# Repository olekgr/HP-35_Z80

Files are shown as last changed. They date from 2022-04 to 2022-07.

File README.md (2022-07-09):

# HP-35-Z80
Build HP35 scientic calculator clone with Z80 cpu from scratch.

## Intro

This DIY page is about building a HP35 clone. But without using emulators, HP microcode etc. I have always wanted to write original algorithms, created by David S. Cochran and provided by William E. Egbert in 4 editions of 1977's HP Journal, please see <a href="https://github.com/olekgr/HP-35_Z80/tree/main/arch">arch</a>.

As the original HP35 was built 50 years ago, this is a good time to do the same.

All fuctions are written with BCD arithmetic, I haven't used BCD - to binary conversion.

## Number format

For this HP35 clone, I chose a BCD floating point format. It uses an exponent byte, a sign byte and eight bytes of fractional part  (80 bits total). 

The sign byte holds 0x00 for positive numbers and 0x09 for negative, this byte also can hold other values in case of positive or negative overflow.

The exponent byte is the signed number power of 10, plus the offset 0x80. Note that exponent is not in BCD form, but binary. This greatly simplifies addition and substraction algorithms. Range is limited to 10^-99 and 10^99.

The fractional part is represented as 16 BCD digits packed two per byte, with an implied decimal point after the first digit (normalized form).

Only the first 12 digits are always displayed to the user; the last 4 digits exists to maintain precision (guard digits). All internal calculations are done with 16 digits, next the displayed result is always rounded to 12 digits.

As an examples:

1 is stored as 80_00_10_00_00_00_00_00_00_00

0.1 is stored as 7f_00_10_00_00_00_00_00_00_00

123 is stored as 82_00_12_30_00_00_00_00_00_00

pi/4 is stored  as 7f_00_78_53_98_16_33_97_44_83

## Negative numbers

Negative numbers are always stored as their 10's complement, with 0x09 at sign position. For example:

-1 is stored as 80_09_90_00_00_00_00_00_00_00

-12 is stored as 81_09_88_00_00_00_00_00_00_00

## Why Z80?

The Z80 is only four years younger than the HP35 :)

It has few instructions useful for making BCD arithmetic:

* RLD - rotate left decimal (used for shifting BCD numbers to the left)

* RRD - rotate right decimal (used for shifting BCD numbers to the right)

* DAA - decimal accumulator adjust (addition and substraction of BCD numbers)

## Speed

Calculations are fast, much faster than original HP35, we get the result immediately after pressing the key.

## Operating

I have made every effort to make this calculator work exactly like the original. Some functions were simple, others (most notably the CHS key which changes the sign of a number before or after it was entered) difficult. Either way, the calculator executes all the examples in the HP35 manual the same way. I have to say I use this calculator every day and it does a great job.

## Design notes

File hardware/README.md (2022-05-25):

# HP-35-Z80
EAGLE PCB source files, schematic, gerbers etc.

## Hardware
The hardware is made as simple as possible. It consists of a Z80 CPU, 8K RAM, 8K ROM, input and output buffers and a simple address decoder. The main program takes about 6K, so it fits easily in 8K EEPROM. I chose 8K RAM (6264) only and because of availability, not need, I think 1-2K would be enough for stack and variables.

## Memory map
0000h-2000h ROM

8000h-A000h RAM

## BOM
* IC1 - Z80 - main CPU
* IC2 - AT28C64 - ROM
* IC3 - 6264 - RAM
* IC4 - 74HCT32 - control signals (memory read, write)
* IC5 - 74HCT154 - display multiplexer
* IC6 - 74HCT138 - address decoder (only 3 periph used)
* IC7 - 74HCT541 - keyboard input
* IC8, IC9 - 74HCT574 - digit and position for multiplexing 7-seg display
* OSC - 8MHz DIL14 - main clock

All SMT components in 1206 case (except C11 - "D" case)
* C1 - 10u 
* R1..R9 - 10k 
* C2..C10 100n
* R10..R17 - 220R (HP used inductors here for power saving :)
* DIS1..4 - common cathode 4x7 segment display (eg. SH5461AS)
* X1,X2 - USB MINI sockets (+5V power supply, for convenience left and right side)
* keys 1..35 Cherry MX switches

## Errors

None found :)

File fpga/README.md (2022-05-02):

# HP-35-Z80
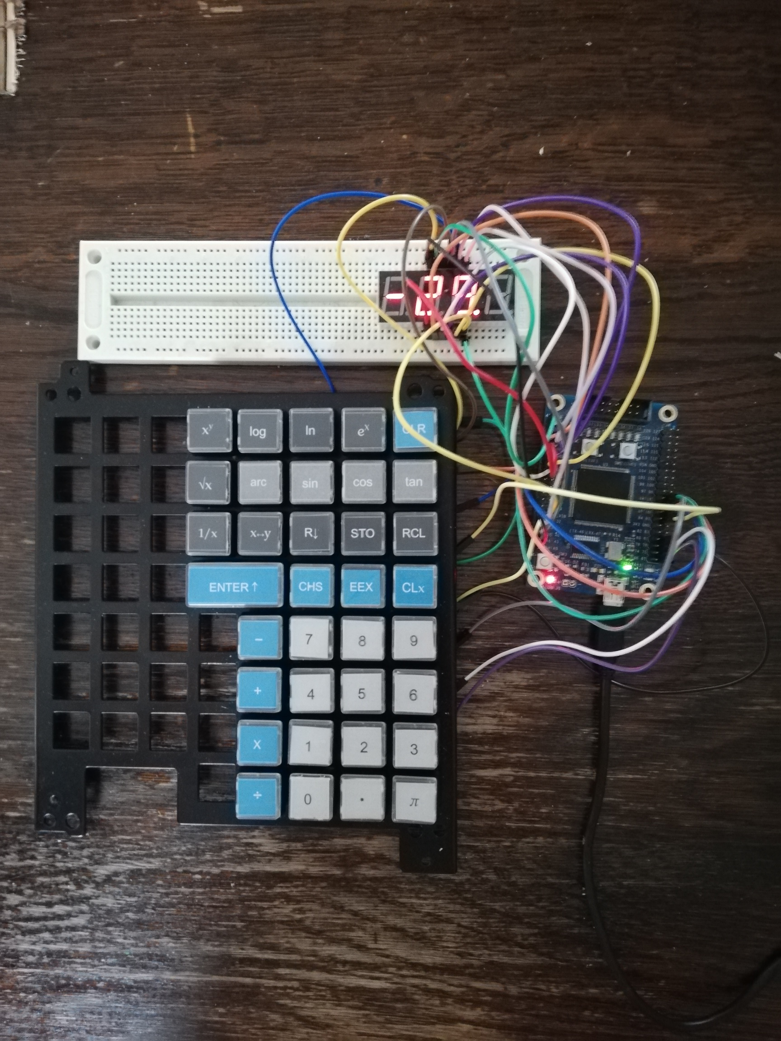
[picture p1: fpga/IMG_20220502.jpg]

What is FPGA doing in this project? Well, beeing VHDL fan, all work on the HP35 clone was done on the thing shown in the photo. In the xilinx XC6SLX9 I implemented the T80 core from Opencores with all accompanying circuits. The keyboard is from an old cash register. And only one 4 digit display.

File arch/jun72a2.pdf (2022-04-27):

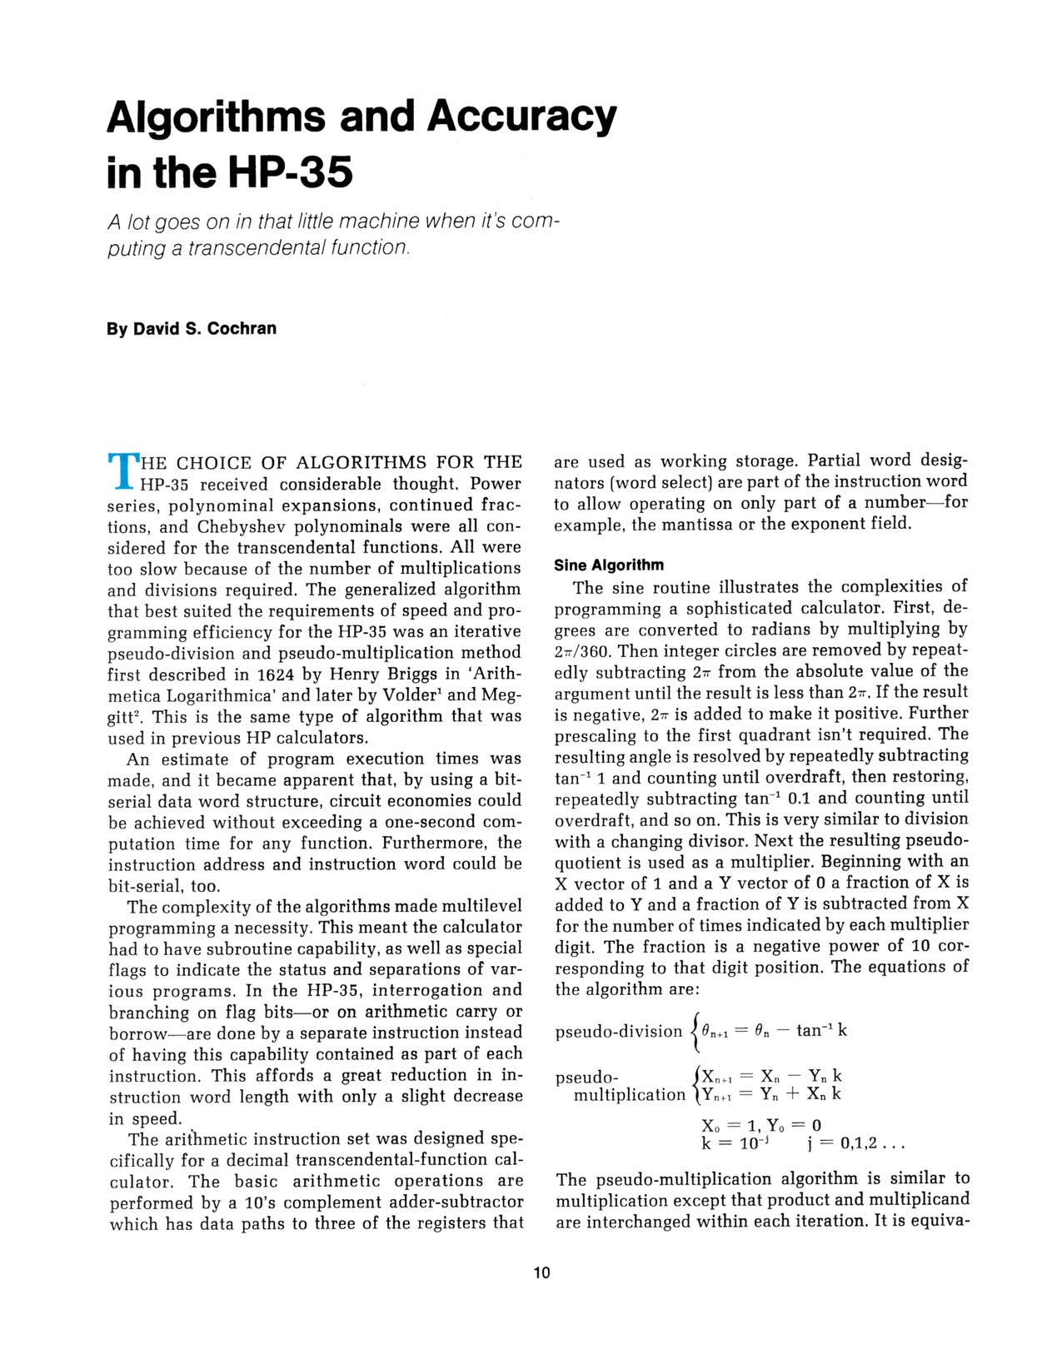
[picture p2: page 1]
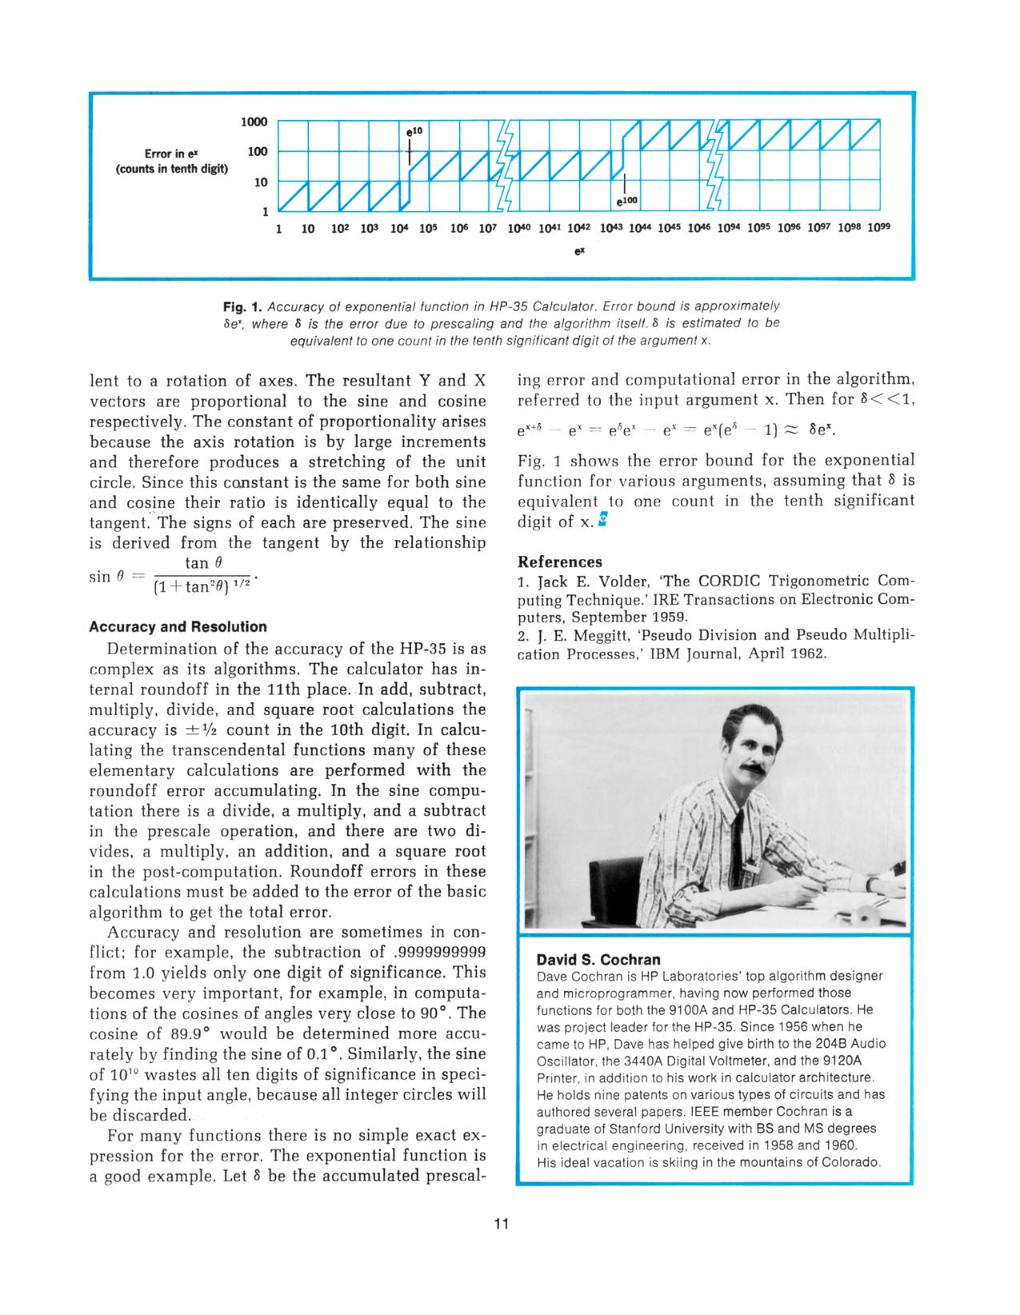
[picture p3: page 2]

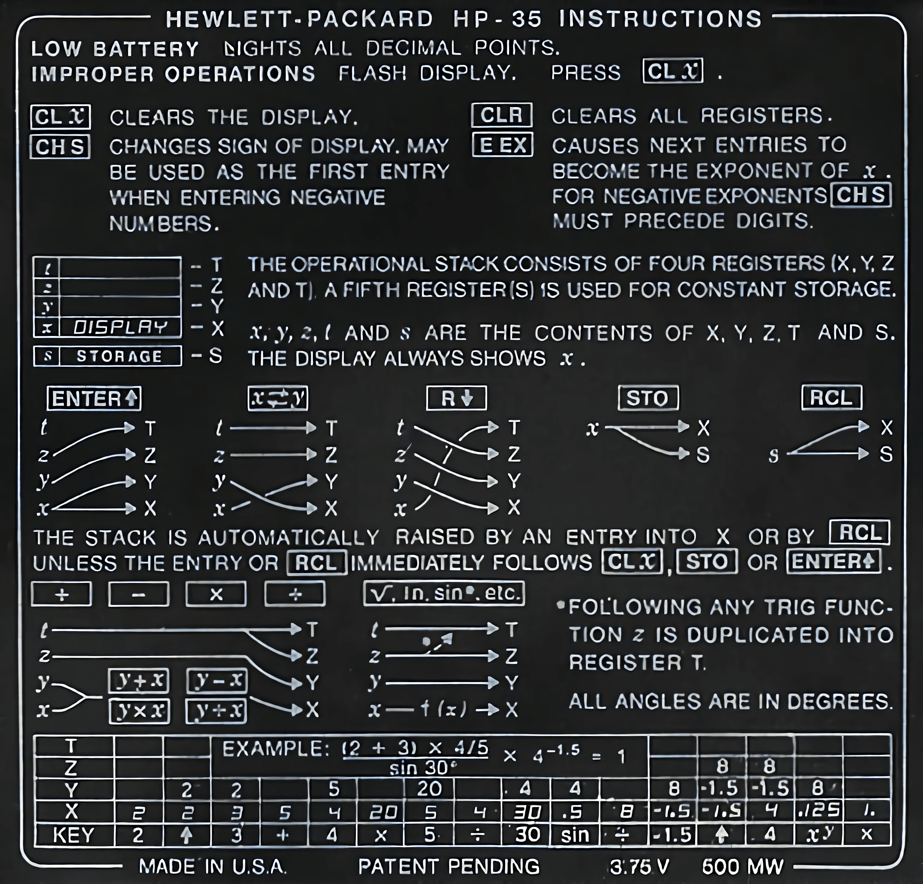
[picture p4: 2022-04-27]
arch/HP35_Backlabel.png

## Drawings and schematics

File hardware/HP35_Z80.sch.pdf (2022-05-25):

8Q | 12 7Q | 13 6Q | 14 5Q | 15 4Q | 16 3Q | 17 2Q | 18 1Q | 19
8Q | 12 7Q | 13 6Q | 14 5Q | 15 4Q | 16 3Q | 17 2Q | 18 1Q | 19

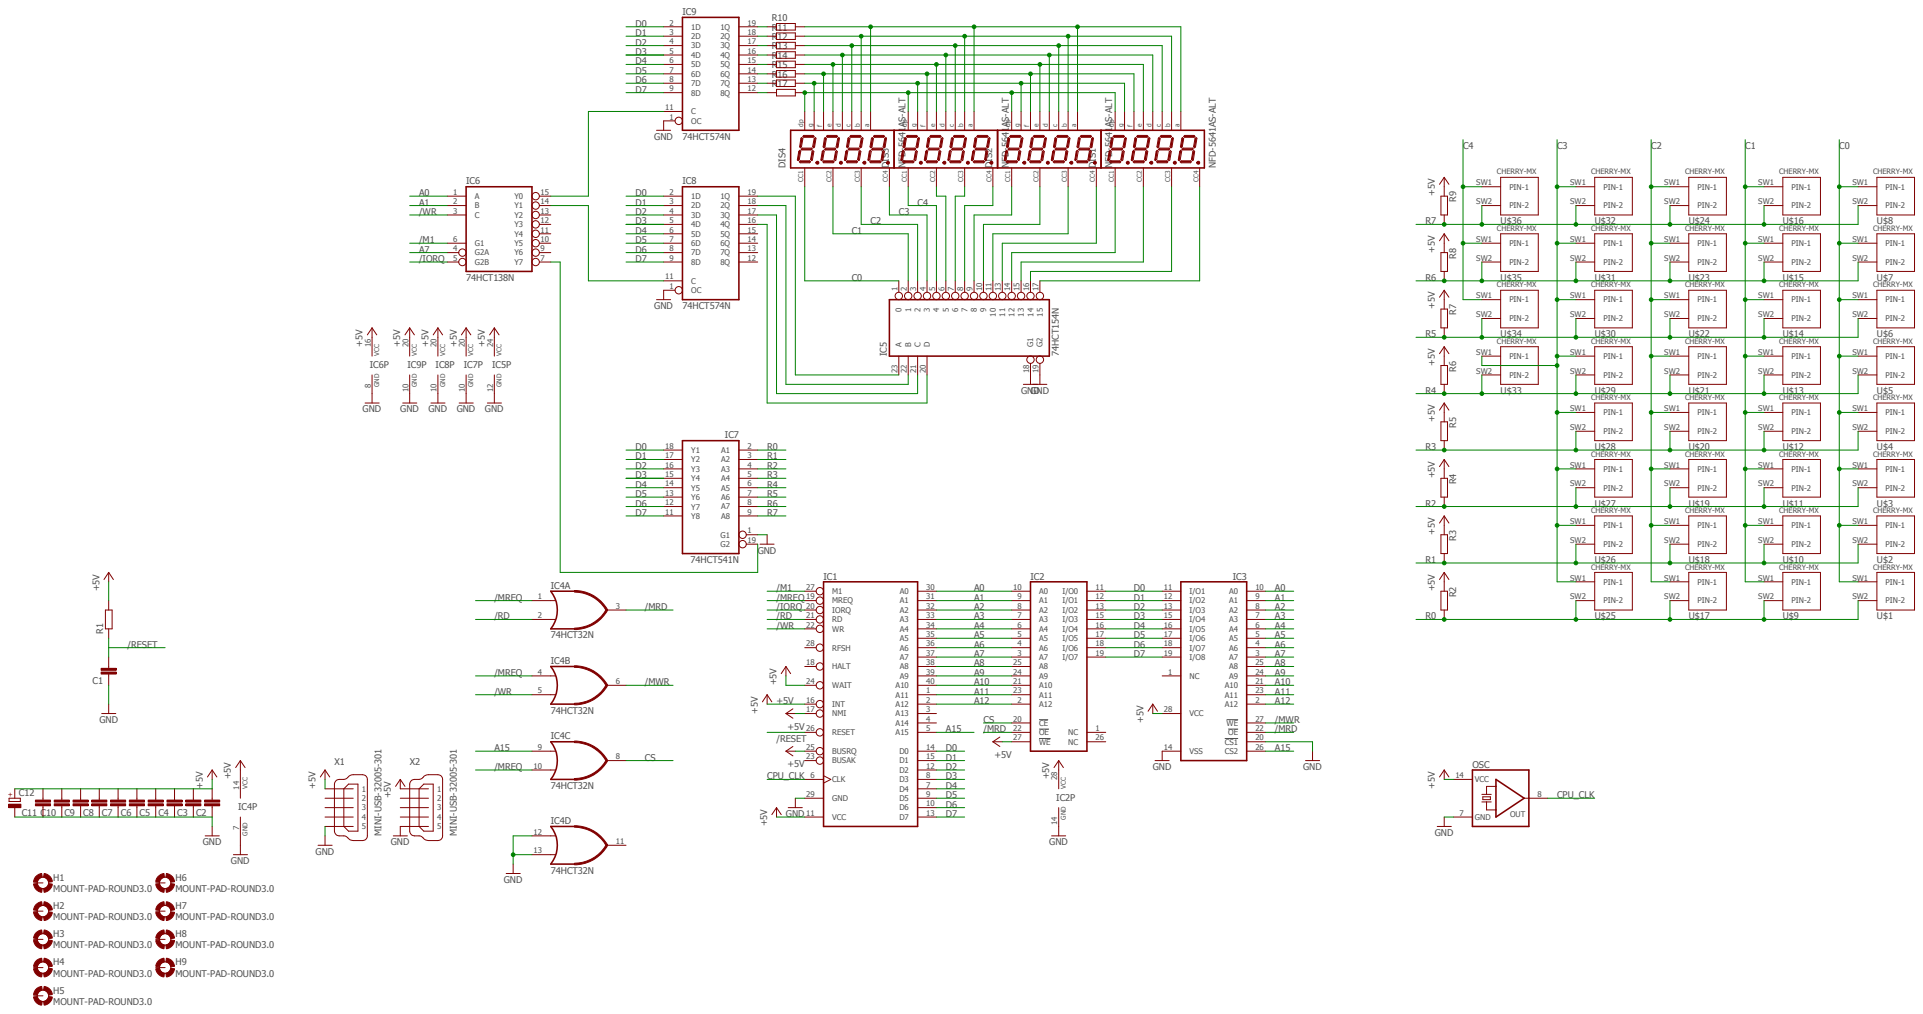
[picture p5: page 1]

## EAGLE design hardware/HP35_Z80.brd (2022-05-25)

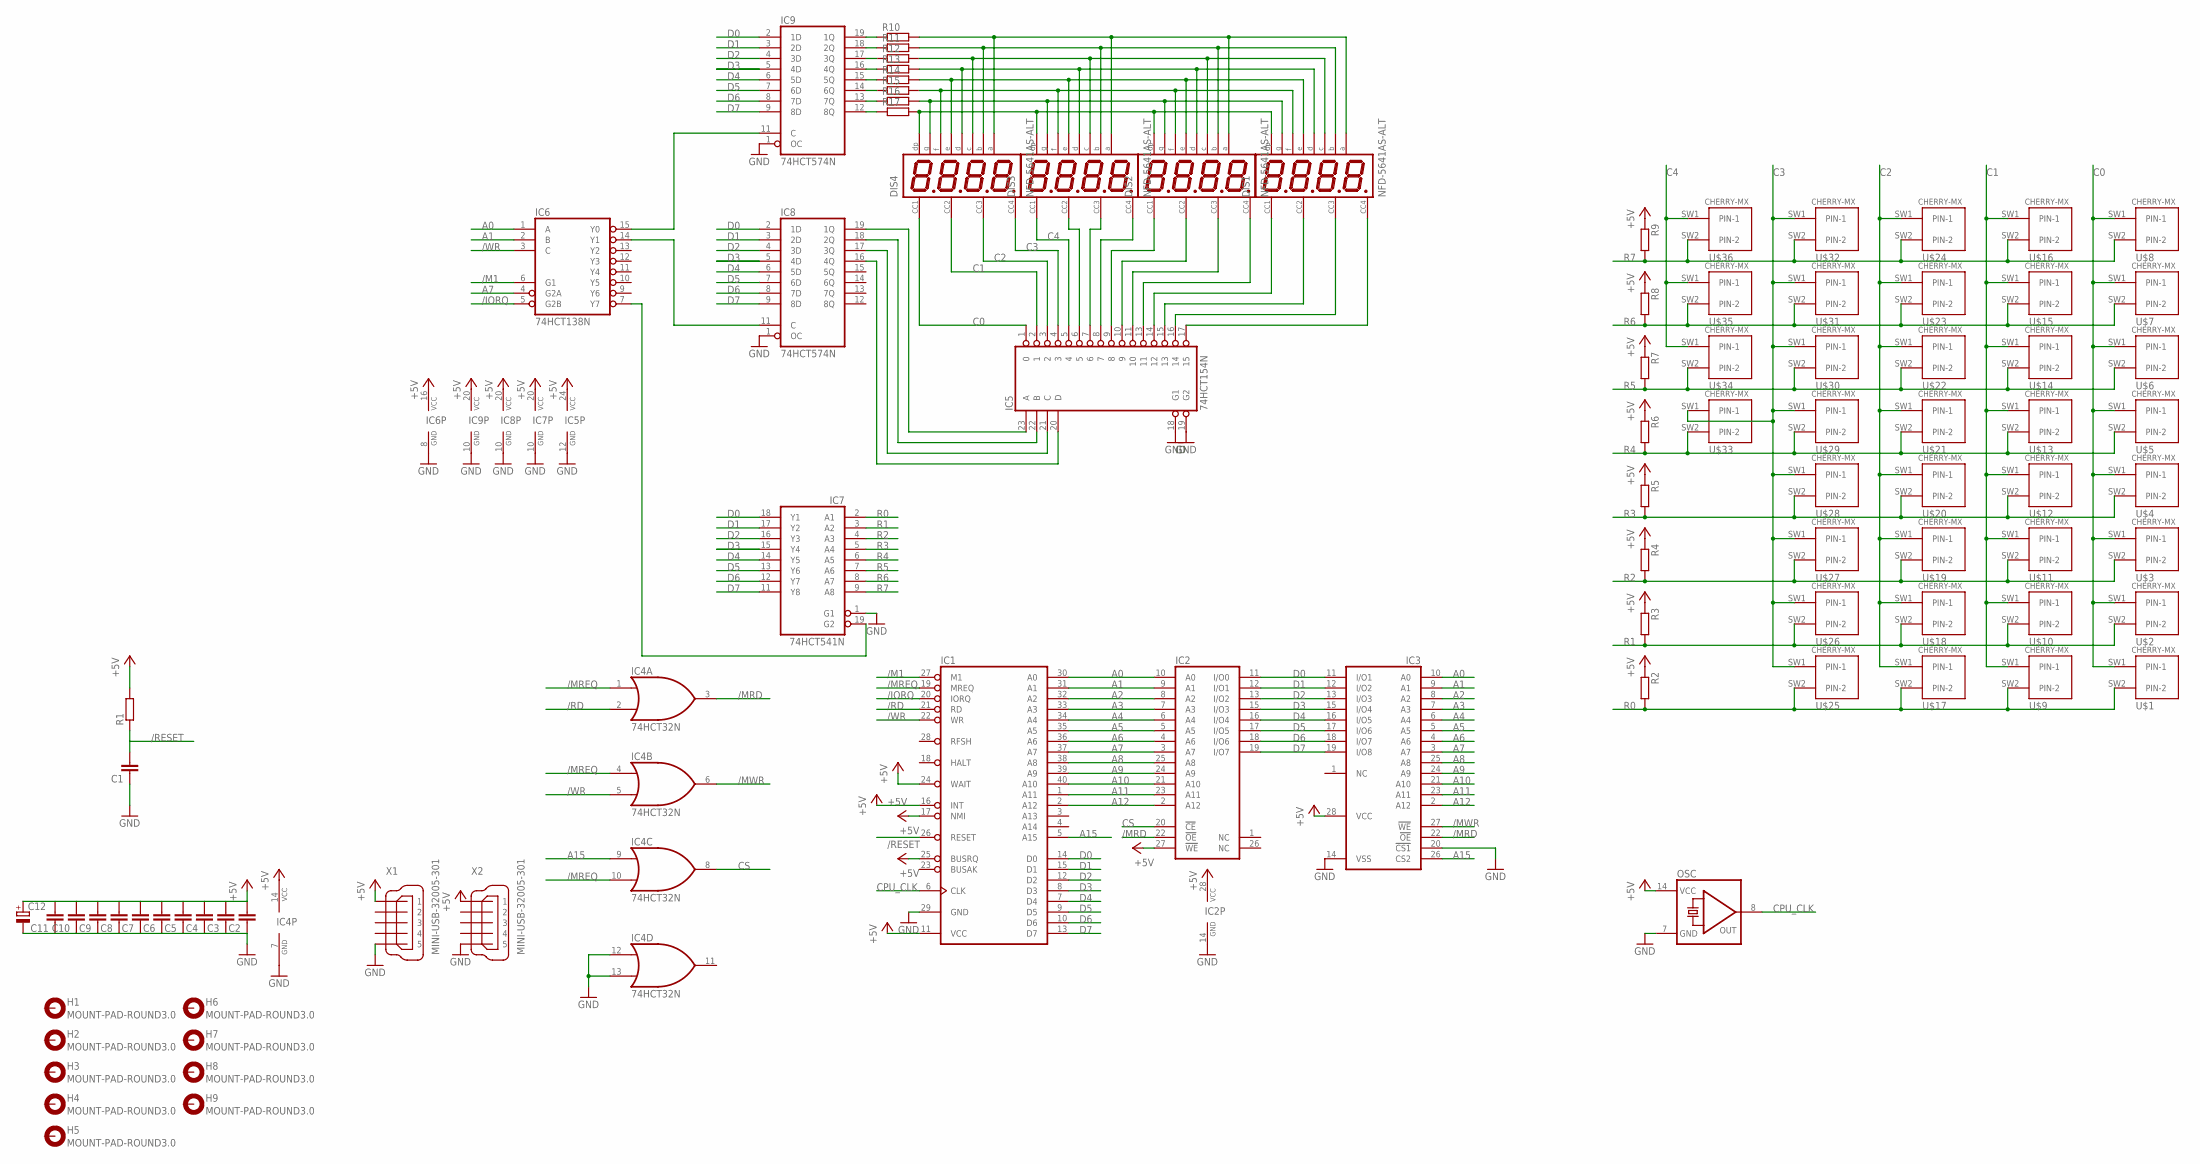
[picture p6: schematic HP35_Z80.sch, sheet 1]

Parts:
C1, C2, C3, C4, C5, C6, C7, C8, C9, C10, C11: C-EUC1206; C1206
C12: CPOL-EUSMCD; SMC_D
DIS1, DIS2, DIS3, DIS4: NFD-5641AS-ALT; NFD-5641
H1, H2, H3, H4, H5, H6, H7, H8, H9: MOUNT-PAD-ROUND3.0; 3,0-PAD
IC1: Z80CPU; DIL40
IC2: 78C64P; DIL28-6
IC3: 6264A; DIL28-6
IC4: 74HCT32N; DIL14
IC5: 74HCT154N; DIL24-6
IC6: 74HCT138N; DIL16
IC7: 74HCT541N; DIL20
IC8, IC9: 74HCT574N; DIL20
OSC: QG5860; DIL14S
R1, R2, R3, R4, R5, R6, R7, R8, R9, R10, R11, R12, R13, R14, R15, R16, R17: R-EU_R1206; R1206
U$1, U$2, U$3, U$4, U$5, U$6, U$7, U$8, U$9, U$10, U$11, U$12, U$13, U$14, U$15, U$16, U$17, U$18, U$19, U$20, U$21, U$22, U$23, U$24, U$25, U$26, U$27, U$28, U$29, U$30, U$31, U$32, U$33, U$34, U$35, U$36: CHERRY-MX
X1, X2: MINI-USB-32005-301; 32005-301

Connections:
+5V: C2.2, C3.2, C4.2, C5.2, C6.2, C7.2, C8.2, C9.2, C10.2, C11.2, C12.+, IC1.11 (VCC), IC1.16 (INT), IC1.17 (NMI), IC1.24 (WAIT), IC1.25 (BUSRQ), IC2.27 (!WE), IC2.28 (VCC), IC3.28 (VCC), IC4.14 (VCC), IC5.24 (VCC), IC6.16 (VCC), IC7.20 (VCC), IC8.20 (VCC), IC9.20 (VCC), OSC.14 (VCC), R1.2, R2.1, R3.1, R4.1, R5.1, R6.1, R7.1, R8.1, R9.1, X1.1, X2.1
/IORQ: IC1.20 (IORQ), IC6.5 (G2B)
/M1: IC1.27 (M1), IC6.6 (G1)
/MRD: IC2.22 (!OE), IC3.22 (!OE), IC4.3 (O)
/MREQ: IC1.19 (MREQ), IC4.1 (I0), IC4.4 (I0), IC4.10 (I1)
/MWR: IC3.27 (!WE), IC4.6 (O)
/RD: IC1.21 (RD), IC4.2 (I1)
/RESET: C1.2, IC1.26 (RESET), R1.1
/WR: IC1.22 (WR), IC4.5 (I1), IC6.3 (C)
A0: IC1.30 (A0), IC2.10 (A0), IC3.10 (A0), IC6.1 (A)
A1: IC1.31 (A1), IC2.9 (A1), IC3.9 (A1), IC6.2 (B)
A2: IC1.32 (A2), IC2.8 (A2), IC3.8 (A2)
A3: IC1.33 (A3), IC2.7 (A3), IC3.7 (A3)
A4: IC1.34 (A4), IC2.6 (A4), IC3.6 (A4)
A5: IC1.35 (A5), IC2.5 (A5), IC3.5 (A5)
A6: IC1.36 (A6), IC2.4 (A6), IC3.4 (A6)
A7: IC1.37 (A7), IC2.3 (A7), IC3.3 (A7), IC6.4 (G2A)
A8: IC1.38 (A8), IC2.25 (A8), IC3.25 (A8)
A9: IC1.39 (A9), IC2.24 (A9), IC3.24 (A9)
A10: IC1.40 (A10), IC2.21 (A10), IC3.21 (A10)
A11: IC1.1 (A11), IC2.23 (A11), IC3.23 (A11)
A12: IC1.2 (A12), IC2.2 (A12), IC3.2 (A12)
A15: IC1.5 (A15), IC3.26 (CS2), IC4.9 (I0)
C0: DIS4.P$12, IC5.1 (0), U$1.SW1 (PIN-1), U$2.SW1 (PIN-1), U$3.SW1 (PIN-1), U$4.SW1 (PIN-1), U$5.SW1 (PIN-1), U$6.SW1 (PIN-1), U$7.SW1 (PIN-1), U$8.SW1 (PIN-1)
C1: DIS4.P$9, IC5.2 (1), U$9.SW1 (PIN-1), U$10.SW1 (PIN-1), U$11.SW1 (PIN-1), U$12.SW1 (PIN-1), U$13.SW1 (PIN-1), U$14.SW1 (PIN-1), U$15.SW1 (PIN-1), U$16.SW1 (PIN-1)
C2: DIS4.P$8, IC5.3 (2), U$17.SW1 (PIN-1), U$18.SW1 (PIN-1), U$19.SW1 (PIN-1), U$20.SW1 (PIN-1), U$21.SW1 (PIN-1), U$22.SW1 (PIN-1), U$23.SW1 (PIN-1), U$24.SW1 (PIN-1)
C3: DIS4.P$6, IC5.4 (3), U$25.SW1 (PIN-1), U$26.SW1 (PIN-1), U$27.SW1 (PIN-1), U$28.SW1 (PIN-1), U$29.SW1 (PIN-1), U$30.SW1 (PIN-1), U$31.SW1 (PIN-1), U$32.SW1 (PIN-1), U$33.SW1 (PIN-1)
C4: DIS3.P$12, IC5.5 (4), U$34.SW1 (PIN-1), U$35.SW1 (PIN-1), U$36.SW1 (PIN-1)
CPU_CLK: IC1.6 (CLK), OSC.8 (OUT)
CS: IC2.20 (!CE), IC4.8 (O)
D0: IC1.14 (D0), IC2.11 (I/O0), IC3.11 (I/O1), IC7.18 (Y1), IC8.2 (1D), IC9.2 (1D)
D1: IC1.15 (D1), IC2.12 (I/O1), IC3.12 (I/O2), IC7.17 (Y2), IC8.3 (2D), IC9.3 (2D)
D2: IC1.12 (D2), IC2.13 (I/O2), IC3.13 (I/O3), IC7.16 (Y3), IC8.4 (3D), IC9.4 (3D)
D3: IC1.8 (D3), IC2.15 (I/O3), IC3.15 (I/O4), IC7.15 (Y4), IC8.5 (4D), IC9.5 (4D)
D4: IC1.7 (D4), IC2.16 (I/O4), IC3.16 (I/O5), IC7.14 (Y5), IC8.6 (5D), IC9.6 (5D)
D5: IC1.9 (D5), IC2.17 (I/O5), IC3.17 (I/O6), IC7.13 (Y6), IC8.7 (6D), IC9.7 (6D)
D6: IC1.10 (D6), IC2.18 (I/O6), IC3.18 (I/O7), IC7.12 (Y7), IC8.8 (7D), IC9.8 (7D)
D7: IC1.13 (D7), IC2.19 (I/O7), IC3.19 (I/O8), IC7.11 (Y8), IC8.9 (8D), IC9.9 (8D)
GND: C1.1, C2.1, C3.1, C4.1, C5.1, C6.1, C7.1, C8.1, C9.1, C10.1, C11.1, C12.-, IC1.29 (GND), IC2.14 (GND), IC3.14 (VSS), IC3.20 (!CS1), IC4.7 (GND), IC4.12 (I0), IC4.13 (I1), IC5.12 (GND), IC5.18 (G1), IC5.19 (G2), IC6.8 (GND), IC7.1 (G1), IC7.10 (GND), IC8.1 (OC), IC8.10 (GND), IC9.1 (OC), IC9.10 (GND), OSC.7 (GND), X1.5, X2.5
unnamed: IC6.15 (Y0), IC9.11 (C)
unnamed: IC5.20 (D), IC8.16 (4Q)
unnamed: IC6.14 (Y1), IC8.11 (C)
unnamed: IC5.21 (C), IC8.17 (3Q)
unnamed: IC5.22 (B), IC8.18 (2Q)
unnamed: IC5.23 (A), IC8.19 (1Q)
unnamed: IC6.7 (Y7), IC7.19 (G2)
unnamed: IC9.12 (8Q), R17.1
unnamed: IC9.13 (7Q), R16.1
unnamed: IC9.14 (6Q), R15.1
unnamed: IC9.15 (5Q), R14.1
unnamed: DIS3.P$9, IC5.6 (5)
unnamed: DIS3.P$8, IC5.7 (6)
unnamed: DIS3.P$6, IC5.8 (7)
unnamed: DIS2.P$12, IC5.9 (8)
unnamed: DIS2.P$9, IC5.10 (9)
unnamed: DIS2.P$8, IC5.11 (10)
unnamed: DIS2.P$6, IC5.13 (11)
unnamed: DIS1.P$12, IC5.14 (12)
unnamed: DIS1.P$9, IC5.15 (13)
unnamed: DIS1.P$8, IC5.16 (14)
unnamed: DIS1.P$6, IC5.17 (15)
unnamed: IC9.16 (4Q), R13.1
unnamed: IC9.17 (3Q), R12.1
unnamed: IC9.18 (2Q), R11.1
unnamed: IC9.19 (1Q), R10.1
unnamed: DIS1.P$11, DIS2.P$11, DIS3.P$11, DIS4.P$11, R10.2
unnamed: DIS1.P$3, DIS2.P$3, DIS3.P$3, DIS4.P$3, R17.2
unnamed: DIS1.P$5, DIS2.P$5, DIS3.P$5, DIS4.P$5, R16.2
unnamed: DIS1.P$10, DIS2.P$10, DIS3.P$10, DIS4.P$10, R15.2
unnamed: DIS1.P$1, DIS2.P$1, DIS3.P$1, DIS4.P$1, R14.2
unnamed: DIS1.P$7, DIS2.P$7, DIS3.P$7, DIS4.P$7, R11.2
unnamed: DIS1.P$4, DIS2.P$4, DIS3.P$4, DIS4.P$4, R12.2
unnamed: DIS1.P$2, DIS2.P$2, DIS3.P$2, DIS4.P$2, R13.2
R0: IC7.2 (A1), R2.2, U$1.SW2 (PIN-2), U$9.SW2 (PIN-2), U$17.SW2 (PIN-2), U$25.SW2 (PIN-2)
R1: IC7.3 (A2), R3.2, U$2.SW2 (PIN-2), U$10.SW2 (PIN-2), U$18.SW2 (PIN-2), U$26.SW2 (PIN-2)
R2: IC7.4 (A3), R4.2, U$3.SW2 (PIN-2), U$11.SW2 (PIN-2), U$19.SW2 (PIN-2), U$27.SW2 (PIN-2)
R3: IC7.5 (A4), R5.2, U$4.SW2 (PIN-2), U$12.SW2 (PIN-2), U$20.SW2 (PIN-2), U$28.SW2 (PIN-2)
R4: IC7.6 (A5), R6.2, U$5.SW2 (PIN-2), U$13.SW2 (PIN-2), U$21.SW2 (PIN-2), U$29.SW2 (PIN-2), U$33.SW2 (PIN-2)
R5: IC7.7 (A6), R7.2, U$6.SW2 (PIN-2), U$14.SW2 (PIN-2), U$22.SW2 (PIN-2), U$30.SW2 (PIN-2), U$34.SW2 (PIN-2)
R6: IC7.8 (A7), R8.2, U$7.SW2 (PIN-2), U$15.SW2 (PIN-2), U$23.SW2 (PIN-2), U$31.SW2 (PIN-2), U$35.SW2 (PIN-2)
R7: IC7.9 (A8), R9.2, U$8.SW2 (PIN-2), U$16.SW2 (PIN-2), U$24.SW2 (PIN-2), U$32.SW2 (PIN-2), U$36.SW2 (PIN-2)

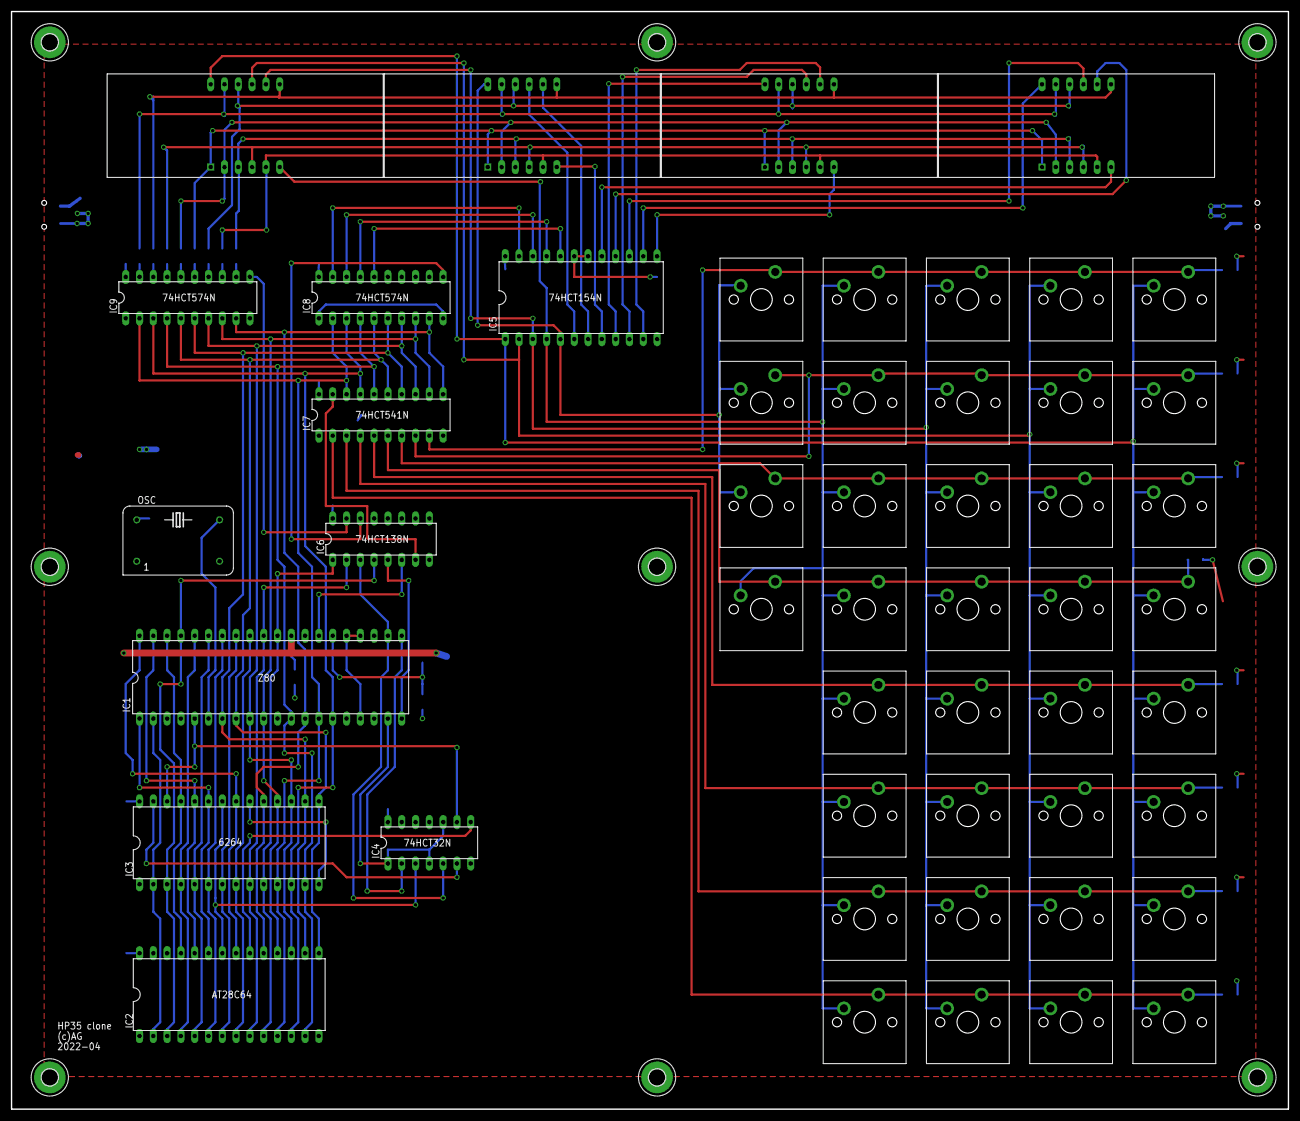
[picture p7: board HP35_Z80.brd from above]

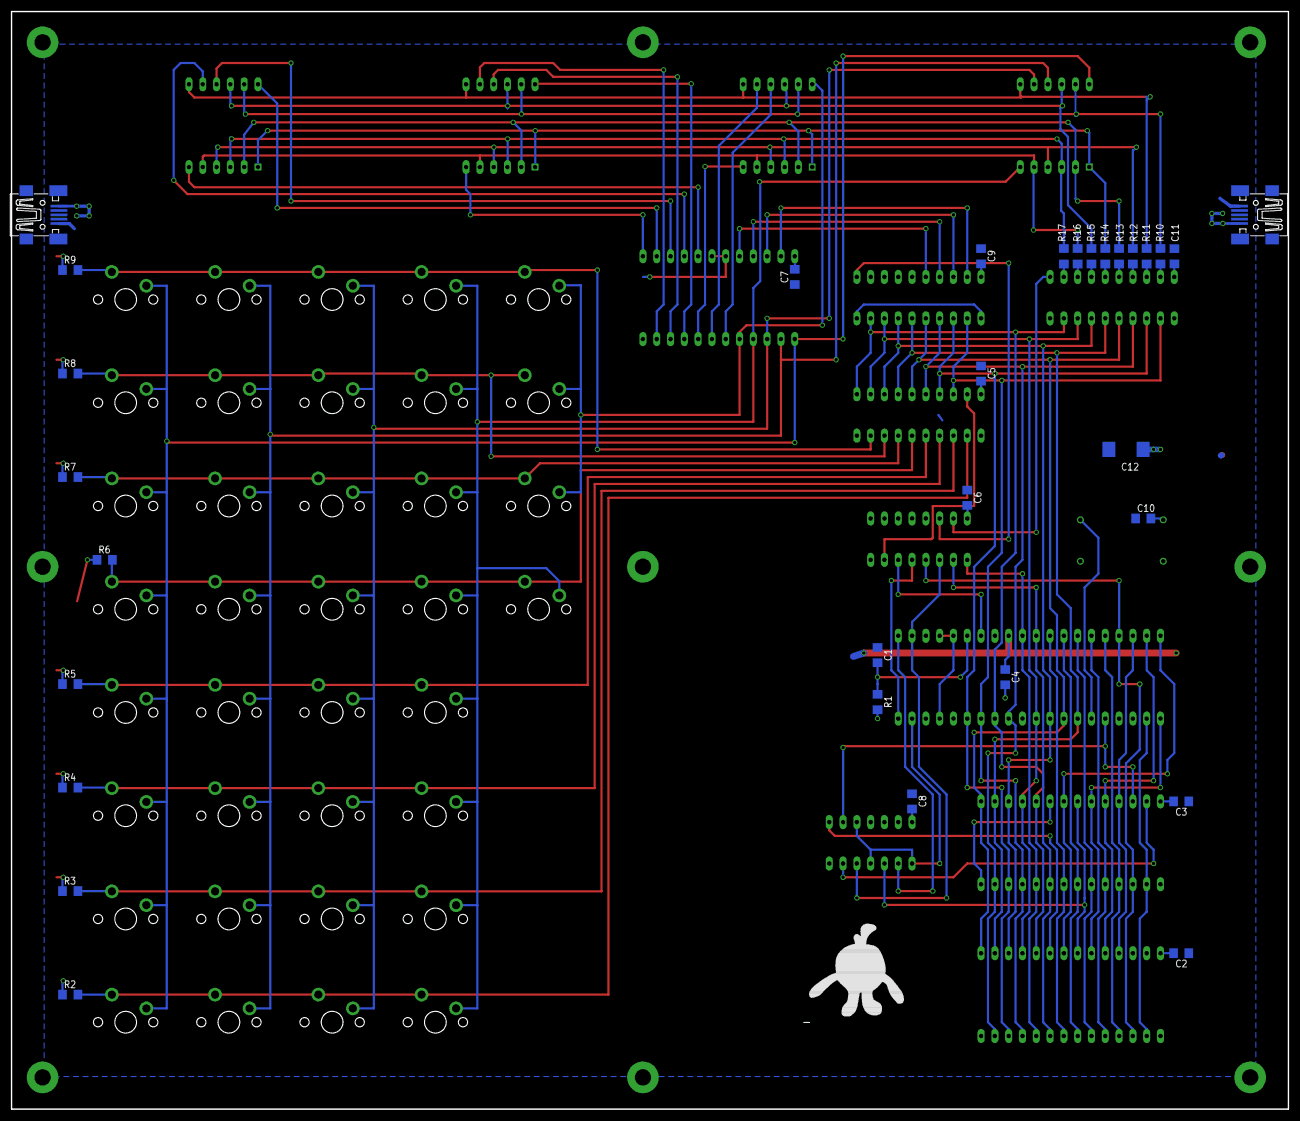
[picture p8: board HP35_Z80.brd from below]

Board: 2 copper layers, 235.0 x 202.0 mm, 90 parts (31 on the bottom side), 81 nets.

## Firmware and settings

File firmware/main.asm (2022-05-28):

;Copyright (c) 2022 Aleksander Grodzki
; 
;Permission is hereby granted, free of charge, to any person obtaining a copy
;of this software and associated documentation files (the "Software"), to deal
;in the Software without restriction, including without limitation the rights
;to use, copy, modify, merge, publish, distribute, sublicense, and/or sell
;copies of the Software, and to permit persons to whom the Software is
;furnished to do so, subject to the following conditions:
; 
;The above copyright notice and this permission notice shall be included in all
;copies or substantial portions of the Software.
; 
;THE SOFTWARE IS PROVIDED "AS IS", WITHOUT WARRANTY OF ANY KIND, EXPRESS OR
;IMPLIED, INCLUDING BUT NOT LIMITED TO THE WARRANTIES OF MERCHANTABILITY,
;FITNESS FOR A PARTICULAR PURPOSE AND NONINFRINGEMENT. IN NO EVENT SHALL THE
;AUTHORS OR COPYRIGHT HOLDERS BE LIABLE FOR ANY CLAIM, DAMAGES OR OTHER
;LIABILITY, WHETHER IN AN ACTION OF CONTRACT, TORT OR OTHERWISE, ARISING FROM,
;OUT OF OR IN CONNECTION WITH THE SOFTWARE OR THE USE OR OTHER DEALINGS IN THE
;SOFTWARE.

            .ORG    0000H 
            LD      sp,memory_top 
            DI       
            JP      main 

MEMORY_TOP  EQU     0a000h

include arith.asm
include romtables.asm
include mult.asm
include display.asm
include pack.asm
include sqrt.asm
include ln.asm
include exp.asm
include atan.asm
include meggitt.asm
include numbers.asm
include stack.asm
include trig.asm
include utils.asm

;-----------------------------------------------------------------------------
;	main program starts here :)
MAIN:                
            LD      hl,ROM 
            LD      de,KEY 
            LD      bc,01bdh 
            LDIR     
            LD      hl,KZERO 
            CALL    display 
MAIN1:               
            CALL    key_scan 
            CALL    key_exec 
            JP      main1 

;-----------------------------------------------------------------------------
;	keyboard scanning high level
KEY_SCAN:            
            CALL    scan 
            LD      a,(KEY) 
            CP      0ffh 
            JR      nz,key_scan 
            CALL    deb 

KEY_SCAN1:           
            CALL    scan 
            LD      a,(KEY) 
            CP      0ffh 
            JR      z,key_scan1 
            CALL    deb 
            RET      
;-----------------------------------------------------------------------------
;	keyboard debounce
DEB:                 
            LD      b,0 
DEB1:                
            DEC     b 
            JR      nz,deb1 
            RET      

;-----------------------------------------------------------------------------
;	keyboard scanning and display multiplexing, low level
SCAN:                
            LD      c,16 
            LD      e,0 
            LD      d,0 
            LD      a,0ffh 
            LD      (KEY),a 
            LD      hl,DISP_BUFFER 
SCAN1:               
            LD      a,e 
            OUT     (1),a 
            LD      a,(hl) 
            OUT     (0),a 
            LD      b,80 ;ON
WAIT1:               
            DEC     b 
            JR      nz,wait1 
            XOR     a 
            OUT     (0),a ;OFF

            IN      a,(3)
            LD      b,8 
SHIFT_KEY:           
            RRA      
            JR      c,next_key 
            PUSH    af 
            LD      a,d 
            LD      (KEY),a 
            POP     af 
NEXT_KEY:            
            INC     d 
            DEC     b 
            JR      nz,shift_key 
            INC     e 
            INC     hl 
            DEC     c 
            JR      nz,scan1 
            RET      

;-----------------------------------------------------------------------------
;	key execution
KEY_EXEC:            
            CP      0 ;pi
            JR      nz,code1 
            CALL    stack_up 
            LD      hl,KPI 
            LD      de,XREG 
            CALL    fcopy ;copy PI to XREG
            LD      hl,XREG 
            CALL    fround 
            CALL    display ;write XREG to DISP_BUFFER
            CALL    clear_flags 
            RET      
CODE1:               
            CP      8 ;dot
            JR      nz,code2 
            CALL    dot ;see numbers.asm :)
            RET      
CODE2:               
            CP      16 ;0
            JR      nz,code3 
            LD      a,0 
            CALL    number 
            RET      
CODE3:               
            CP      24 ;/
            JR      nz,code4 
            CALL    pack_keyb_buffer 
            LD      hl,XREG+2 
            LD      b,08h 
            XOR     a 
CODE3_1:             
            OR      (hl) 
            INC     hl 
            DJNZ    code3_1 
            JR      z,code3_2 ;zero check
            LD      hl,YREG 
            LD      de,XREG 
            CALL    div 
            LD      hl,YREG 
            LD      de,XREG 
            CALL    fcopy 
            CALL    stack_down 
            LD      hl,XREG 
            CALL    fround 
            CALL    display 
            CALL    clear_flags 
            RET      
CODE3_2:             
            CALL    error 
            RET      

CODE4:               
            CP      1 ;3
            JR      nz,code5 
            LD      a,3 
            CALL    number 
            RET      
CODE5:               
            CP      9 ;2
            JR      nz,code6 
            LD      a,2 
            CALL    number 
            RET      
CODE6:               
            CP      17 ;1
            JR      nz,code7 
            LD      a,1 
            CALL    number 
            RET      
CODE7:               
            CP      25 ;*
            JR      nz,code8 
            CALL    pack_keyb_buffer 
            LD      hl,XREG 
            LD      de,YREG 
            CALL    mult 
            CALL    stack_down 
            LD      hl,XREG 
            CALL    fround 
            CALL    display 
            CALL    clear_flags 
            RET      
CODE8:               
            CP      2 ;6
            JR      nz,code9 
            LD      a,6 
            CALL    number 
            RET      
CODE9:               
            CP      10 ;5
            JR      nz,code10 
            LD      a,5 
            CALL    number 
            RET      
CODE10:              
            CP      18 ;4
            JR      nz,code11 
            LD      a,4 
            CALL    number 
            RET      
CODE11:              
            CP      26 ;+
            JR      nz,code12 
            CALL    pack_keyb_buffer 
            LD      hl,XREG 
            LD      de,YREG 
            CALL    fadd 
            CALL    stack_down 
            LD      hl,XREG 
            CALL    fround 
            CALL    display 
            CALL    clear_flags 
            RET      
CODE12:              
            CP      3 ;9
            JR      nz,code13 
            LD      a,9 
            CALL    number 
            RET      
CODE13:              
            CP      11 ;8
            JR      nz,code14 
            LD      a,8 
            CALL    number 
            RET      
CODE14:              
            CP      19 ;7
            JR      nz,code15 
            LD      a,7 
            CALL    number 
            RET      
CODE15:              
            CP      27 ;-
            JR      nz,code16 
            CALL    pack_keyb_buffer 
            LD      hl,YREG 
            LD      de,XREG 
            CALL    fsub 
            LD      hl,YREG 
            LD      de,XREG 
            CALL    fcopy 
            CALL    stack_down 
            LD      hl,XREG 
            CALL    fround 
            CALL    display 
            CALL    clear_flags 
            RET      
CODE16:              
            CP      4 ;clx
            JR      nz,code17 
            LD      hl,KZERO 
            LD      de,XREG 
            CALL    fcopy 
            LD      hl,XREG 
            CALL    display 
            CALL    clear_flags 
            LD      hl,LASTKEY 
            LD      (hl),1 
            RET      
CODE17:              
            CP      12 ;eex
            JR      nz,code18 
            LD      a,1h 
            LD      (MODEEEX),a 
            RET      
CODE18:              
            CP      20 ;chs
            JR      nz,code19 
            LD      a,(MODECHS) 
            CP      0 
            JR      z,code18_1 
            LD      a,0 
            JR      code18_2 
CODE18_1:            
            LD      a,1 
CODE18_2:            
            LD      (MODECHS),a 
            CALL    chs 
            RET      
CODE19:              
            CP      28 ;enter
            JR      nz,code20 
            CALL    pack_keyb_buffer 
            CALL    stack_up 
            LD      hl,XREG 
            CALL    display 
            CALL    clear_flags 
            LD      hl,LASTKEY 
            LD      (hl),1 
            RET      
CODE20:              
            CP      5 ; rcl
            JR      nz,code21 
            CALL    pack_keyb_buffer 
            CALL    stack_up 
            LD      hl,SREG 
            LD      de,XREG 
            CALL    fcopy 
            LD      hl,XREG 
            CALL    display 
            CALL    clear_flags 
            LD      hl,LASTKEY 
            LD      (hl),1 
            RET      
CODE21:              
            CP      13 ;sto
            JR      nz,code22 
            CALL    pack_keyb_buffer 
            LD      hl,XREG 
            LD      de,SREG 
            CALL    fcopy 
            LD      hl,XREG 
            CALL    display 
            CALL    clear_flags 
            LD      hl,LASTKEY 
            LD      (hl),1 

            RET      
CODE22:              
            CP      21 ;R down
            JR      nz,code23 
            CALL    pack_keyb_buffer 
            CALL    stack_rotate 
            LD      hl,XREG 
            CALL    display 
            CALL    clear_flags 
            RET      
CODE23:              
            CP      29 ;x<->y
            JR      nz,code24 
            CALL    pack_keyb_buffer 
            LD      hl,XREG 
            LD      de,AREG 
            CALL    fcopy ;store XREG

            LD      hl,YREG 
            LD      de,XREG 
            CALL    fcopy 

            LD      hl,AREG 
            LD      de,YREG 
            CALL    fcopy 

            LD      hl,XREG 
            CALL    display 
            CALL    clear_flags 
            RET      
CODE24:              
            CP      37 ;1/x
            JR      nz,code25 
            CALL    pack_keyb_buffer 
            LD      hl,XREG+2 
            LD      b,08h 
            XOR     a 
CODE24_1:            
            OR      (hl) 
            INC     hl 
            DJNZ    code24_1 
            JR      z,code24_2 ;zero check :)
            LD      hl,KONE 
            LD      de,ONE 
            CALL    fcopy 
            LD      hl,ONE 
            LD      de,XREG 
            CALL    div 
            LD      hl,ONE 
            LD      de,XREG 
            CALL    fcopy 
            LD      hl,KONE 
            LD      de,ONE 
            CALL    fcopy 
            LD      hl,XREG 
            CALL    fround 
            CALL    display 
            CALL    clear_flags 
            RET      
CODE24_2:            
            CALL    error 
            RET      

CODE25:              
            CP      6 ;tan
            JR      nz,code26 
            CALL    pack_keyb_buffer 
            LD      a,(MODEARC) 
            CP      1 
            JR      z,code25_1 
            CALL    convert_to_rad 
            CALL    scale 
            CALL    tan 
            CALL    tan_div 
            JR      code25_2 
CODE25_1:            
            CALL    atan 
            CALL    convert_to_deg 
CODE25_2:            
            CALL    fround 
            CALL    display 
            CALL    clear_flags 
            RET      
CODE26:              
            CP      14 ;cos
            JR      nz,code27 
            CALL    pack_keyb_buffer 
            LD      a,(MODEARC) 
            CP      1 
            JR      z,code26_1 
            CALL    convert_to_rad 
            CALL    scale 
            CALL    trig_sgn_in 
            CALL    cos 
            JR      code26_2 
CODE26_1:            
            LD      a,(XREG) 
            SUB     80h 
            JR      nc,code26_3 
            CALL    acos 
            CALL    convert_to_deg 
CODE26_2:            
            CALL    fround 
            CALL    display 
            CALL    clear_flags 
            RET      
CODE26_3:            
            CALL    error 
            RET      
CODE27:              
            CP      22 ;sin
            JR      nz,code28 
            CALL    pack_keyb_buffer 
            LD      a,(MODEARC) 
            CP      1 
            JR      z,code27_1 
            CALL    convert_to_rad 
            CALL    scale 
            CALL    trig_sgn_in 
            CALL    sin 
            JR      code27_2 
CODE27_1:            
            LD      a,(XREG) 
            SUB     80h 
            JR      nc,code27_3 
            CALL    asin 
            CALL    convert_to_deg 
CODE27_2:            
            CALL    fround 
            CALL    display 
            CALL    clear_flags 
            RET      
CODE27_3:            
            CALL    error 
            RET      
CODE28:              
            CP      30 ;arc
            JR      nz,code29 
            LD      a,1h 
            LD      (MODEARC),a ; set arc mode
            RET      
CODE29:              
            CP      38 ;sqrt
            JR      nz,code30 
            CALL    pack_keyb_buffer 
            LD      a,(XREG+1) 
            CP      9 
            JR      z,code29_1 
            CALL    sqrt 
            CALL    fround 
            CALL    display 
            CALL    clear_flags 
            RET      
CODE29_1:            
            CALL    error 
            RET      
CODE30:              
            CP      7 ;clr
            JR      nz,code31 
            LD      hl,KZERO 
            LD      de,XREG 
            CALL    fcopy 

            LD      hl,KZERO 
            LD      de,YREG 
            CALL    fcopy 

            LD      hl,KZERO 
            LD      de,ZREG 
            CALL    fcopy 

            LD      hl,KZERO 
            LD      de,TREG 
            CALL    fcopy 

            LD      hl,KZERO 
            LD      de,SREG 
            CALL    fcopy 

            LD      hl,XREG 
            CALL    display 
            CALL    clear_flags 
            RET      
CODE31:              
            CP      15 ;ex
            JR      nz,code32 
            CALL    pack_keyb_buffer 
            CALL    ex 
            CALL    fround 
            CALL    display 
            CALL    clear_flags 
            RET      

CODE32:              
            CP      23 ;ln
            JR      nz,code33 
            CALL    pack_keyb_buffer 
            LD      a,(XREG+1) 
            CP      9 
            JR      z,code32_1 
            LD      hl,XREG+2 
            LD      b,08h 
            XOR     a 
CODE32_2:            
            OR      (hl) 
            INC     hl 
            DJNZ    code32_2 
            JR      z,code32_1 ;zero check
            CALL    lnx 
            LD      hl,XREG 
            CALL    fround 
            CALL    display 
            CALL    clear_flags 
            RET      
CODE32_1:            
            CALL    error 
            RET      

CODE33:              
            CP      31 ;log
            JR      nz,code34 
            CALL    pack_keyb_buffer 
            LD      a,(XREG+1) 
            CP      9 
            JR      z,code33_1 
            LD      hl,XREG+2 
            LD      b,08h 
            XOR     a 
CODE33_2:            
            OR      (hl) 
            INC     hl 
            DJNZ    code33_2 
            JR      z,code33_1 ;zero check
            LD      hl,LN10 
            LD      de,AREG 
            CALL    fcopy 
            CALL    lnx 
            LD      hl,XREG 
            LD      de,AREG 
            CALL    div 
            CALL    fround 
            CALL    display 
            CALL    clear_flags 
            RET      
CODE33_1:            
            CALL    error 
            RET      
CODE34:              
            CALL    pack_keyb_buffer ; x^y is last call, no key checking needed
            LD      hl,YREG+2 
            LD      b,08h 
            XOR     a 
CODE34_2:            
            OR      (hl) 
            INC     hl 
            DJNZ    code34_2 
            JR      z,code34_3 
            LD      a,(XREG+1) 
            CP      9 
            JR      z,code34_1 
            LD      a,(YREG+1) 
            CP      9 
            JR      z,code34_4 
            CALL    lnx 
            LD      hl,XREG 
            LD      de,YREG 
            CALL    mult 
            CALL    stack_down 
            CALL    ex 
            LD      hl,XREG 
            CALL    fround 
            CALL    display 
            CALL    clear_flags 
            RET      
CODE34_1:            
            CALL    error 
            RET      
CODE34_3:            ;x^0
            LD      hl,KONE 
            LD      de,XREG 
            CALL    fcopy 
            CALL    display 
            CALL    clear_flags 
            RET      
CODE34_4:            ;x^-y
            LD      hl,YREG 
            CALL    fneg 
            CALL    lnx 
            LD      hl,XREG 
            LD      de,YREG 
            CALL    mult 
            CALL    stack_down 
            CALL    ex 
            LD      hl,KONE 
            LD      de,ONE 
            CALL    fcopy 
            LD      hl,ONE 
            LD      de,XREG 
            CALL    div 
            LD      hl,ONE 
            LD      de,XREG 
            CALL    fcopy 
            LD      hl,KONE 
            LD      de,ONE 
            CALL    fcopy 
            LD      hl,XREG 
            CALL    fround 
            CALL    display 
            CALL    clear_flags 
            RET      
CODE35:              
            LD      a,0ffh ;none
            RET      



include fvar.asm

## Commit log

2022-04-27 add brd
    [Z801.sch]
2022-04-30 clean dir
    [Z801.sch]
2022-05-04 add pcb files
    [HP35_Z80.brd, HP35_Z80.sch, Z801.sch]
2022-05-06 add gerbers
    [HP35_Z80.brd, HP35_Z80.sch]
2022-05-10 update pcb
    [HP35_Z80.brd, HP35_Z80.sch]
2022-05-12 update bom
2022-05-25 update schematic
2022-05-25 update silk
    [HP35_Z80.brd, HP35_Z80.sch]
2022-05-25 update working gerbers
